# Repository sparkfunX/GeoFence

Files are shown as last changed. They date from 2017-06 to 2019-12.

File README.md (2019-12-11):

# GeoFence
A device to monitor when it is inside or outside various GPS waypoints.

# The GeoFence App is no longer supported
Unfortunately, Google has changed the way that they bill their Maps API and because we're no longer building the GeoFence hardware, 
we won't be updating the software. If you're looking for a way to create and enforce your own geofences, we encourage you to check out the [uBlox](https://learn.sparkfun.com/tutorials/getting-started-with-u-center-for-u-blox) products we now carry. If you still have a GeoFence board that you'd like to continue using, you have two options:

1. You can aqcuire your own [Google Maps API Key](https://developers.google.com/maps/documentation/javascript/get-api-key), 
replace our key string in the app source code (index.html line 77), and recompile the app in [electronjs](https://electronjs.org/).

2. You can construct your own configuration string using lat-long data from the source of your choosing and send it to the board using 
a serial terminal. Configuration strings are constructed as follows:

## Complete Configuration String

| Header | Zone 1 | Zone 2 | Zone 3 | Zone 4 | Footer | Chksum | Terminator |
| --- | --- | --- | --- | --- | --- | --- | --- |
| "$\n"  | | | | |  "^\n" | | "$" |

## Zone Configuration

### Null Zone
The device expects to see configurations for each zone, even if the zone is "unprogrammed". Unprogrammed zones are marked with the "X" flag.

| Header |
| ------ |
|  "X\n" |

### Rectangular Zone
Rectangular Boundaries are defined by their NorthEast and SouthWest corners. The Latitude and Longitude of each corner is fixed to 
6 digits of precision after the decimal. Rectangular Zones are marked with the "R" Flag.

| Header | NorthEast Lat | NorthEast Long | SouthWest Lat | SouthWest Long | 
| --- | --- | --- | --- | --- |
|  "R\n" | "xx.xxxxxx\n" |  "-x.xxxxxx\n" | "xxx.xxxxxx\n"| "xx.xxxxxx\n"  |

### Circular Zone
Circular Boundaries are defined by their center coordinate and their radius in meters, rounded to the nearest meter. 
Circular Zones are marked with the "C" flag.

| Header | Center Lat | Center Long | Radius Meters | 
| --- | --- | --- | --- |
|  "C\n" |"x.xxxxxx\n"|"-x.xxxxxx\n"| "xxx\n" |

### Checksum
Strings are transmitted with a checksum for integrity. The checksum is the sum of all character values in the string up to 
the checksum, modulo 256. It is calculated in the App thusly: 

```
  for(var i = 0; i < data.length; i++){
	 chksum = chksum + data.charCodeAt(i); 
  }
  
  chksum = chksum%256;
  ```
  
  The checksum value is written to a single byte and followed by a Line Feed ("\n")
  
### Serial Settings
The configuration string may be sent at any time at 9600 baud. The board will return with "$" if the configuration was succesful, if
the string did not pass checksum, it will return "!"

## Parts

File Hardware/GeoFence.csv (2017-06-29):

Id | Designator | Package | Quantity | Designation | Supplier and ref
1 | R12,R13 | R_0603 | 2 | 4.7k
2 | R4 | R_0603 | 1 | 1k
3 | FRAME1 | CREATIVE_COMMONS | 1 | FRAME-LETTER
4 | C7 | C_0603 | 1 | 2.2uF
5 | C8,C12,C14,C6 | C_0603 | 4 | 1.0uF
6 | C9,C10,C11,C13,C4 | C_0603 | 5 | 0.1uF
7 | J6 | 2X4 | 1 | CONN_04X2
8 | Q1 | RESONATOR-SMD-3.2X1.3 | 1 | 8/16/20MHz
9 | R9,R6,R7,R16 | R_0603 | 4 | 10k
10 | R10,R14,R8,R11 | R_0603 | 4 | 330
11 | R15,R2,R3 | R_0603 | 3 | 470
12 | U2 | SOT353 | 1 | 74LVC1G08SE
13 | U3 | SO16 | 1 | CH340G
14 | U5 | TQFP32-08 | 1 | ATMEGA328
15 | Y1 | CRYSTAL-SMD-3.2X2.5MM | 1 | 12MHz
16 | J4,J5 | 1X04 | 2 | CONN_04
17 | B1 | SparkX-6.8MM_COIN_CELL | 1 | COIN CELL
18 | C1,C2 | C_0603 | 2 | 10pF
19 | C3 | C_0603 | 1 | 10nF
20 | D1,D9 | LED_0603 | 2 | BLUE
21 | D2 | SparkFun-DiscreteSemi-SOD-323 | 1 | 0.5A/40V/420mV
22 | D5,D6,D7,D8 | LED_0603 | 4 | Green
23 | FB1 | L_0603 | 1 | 600Ohm/100MHz
24 | J1 | SparkX-U.FL | 1 | U.FL
25 | J2 | USB-B-MICRO-SMD | 1 | microB
26 | J3 | 2X3 | 1 | AVR_SPI_PROG_3X2PTH
27 | JP2,JP6 | FIDUCIAL-MICRO | 2 | FIDUCIALUFIDUCIAL
28 | JP5 | SMT-JUMPER_2_NC_TRACE_NO-SILK | 1 | ~
29 | L1 | L_0603 | 1 | 33nH/~5%/500mA
30 | R1,R19,R20 | R_0603 | 3 | 1K
31 | S1 | TACTILE_SWITCH_SMD_5.2MM | 1 | Reset
32 | U$1 | SparkX-SPARKX-LARGE | 1 | SPARKX-LOGO5
33 | U1 | SparkX-TITAN_X1_GPS | 1 | TITAN X1 GPS
34 | C15,C5 | C_0603 | 2 | 4.7uF
35 | D10 | SparkFun-DiscreteSemi-SOD-323 | 1 | BAT20J
36 | JP8 | JST-2-PTH | 1 | LiPo
37 | Q2 | SparkFun-DiscreteSemi-SOT23-3 | 1 | 2.5A/30V
38 | R17 | R_0603 | 1 | 2.0k
39 | U6 | SOT23-5 | 1 | MCP73831
40 | U4 | SOT23-5 | 1 | AP2112K-3.3V
41 | D3,D11 | LED_0603 | 2 | Yellow
42 | D4 | LED_0603 | 1 | GREEN
43 | D12 | LED_0603 | 1 | RED

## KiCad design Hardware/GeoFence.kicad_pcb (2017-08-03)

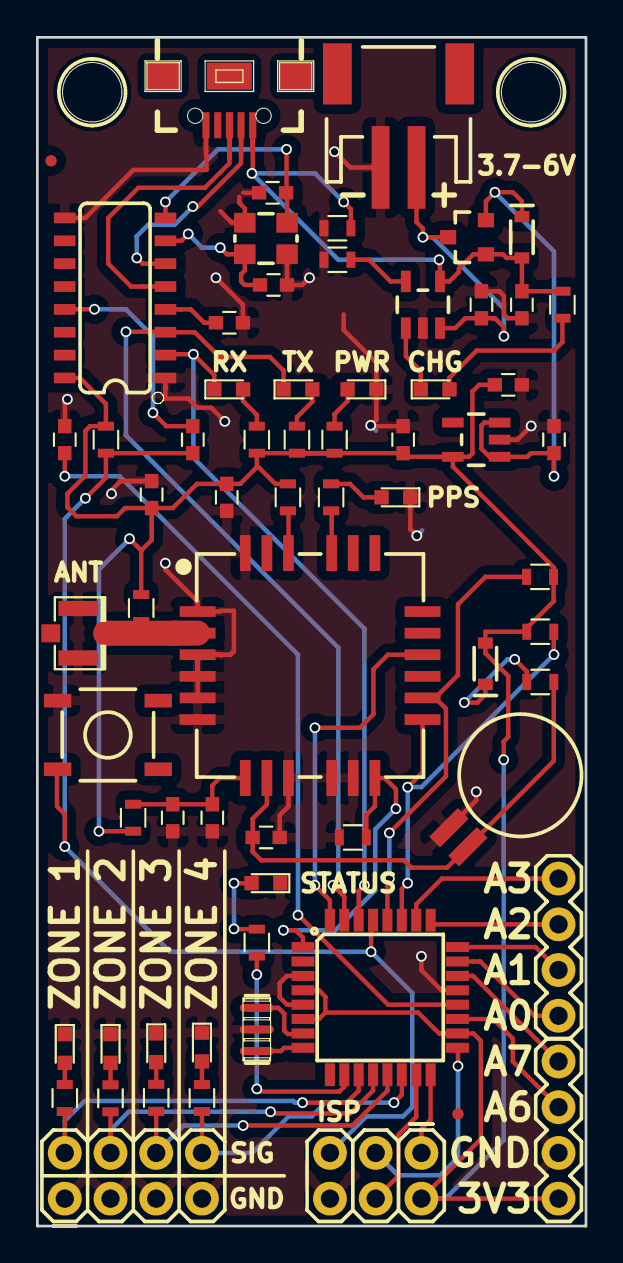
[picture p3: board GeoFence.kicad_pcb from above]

Board: 2 copper layers, 30.5 x 66.0 mm, 68 parts (0 on the bottom side), 53 nets.

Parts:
B1: COIN CELL; SparkX-6.8MM_COIN_CELL
C1, C2: 10pF; C_0603
C3: 10nF; C_0603
C4, C9, C10, C11, C13: 0.1uF; C_0603
C5, C15: 4.7uF; C_0603
C6, C8, C12, C14: 1.0uF; C_0603
C7: 2.2uF; C_0603
D1, D5, D6, D7, D8, D9: Blue; LED_0603
D2: 0.5A/40V/420mV; SparkFun-DiscreteSemi-SOD-323
D3, D11: Yellow; LED_0603
D4: GREEN; LED_0603
D10: BAT20J; SparkFun-DiscreteSemi-SOD-323
D12: Red; LED_0603
FB1: 600Ohm/100MHz; L_0603
H1, H2: STAND-OFF
J1: U.FL; SparkX-U.FL
J2: microB; USB-B-MICRO-SMD
J3: AVR_SPI_PROG_3X2PTH; 2X3
J4, J5: CONN_04; 1X04
J6: CONN_04X2; 2X4
JP2, JP6: FIDUCIALUFIDUCIAL; FIDUCIAL-MICRO
JP8: LiPo; JST-2-SMD
L1: 33nH/~5%/500mA; L_0603
Q1: 8/16/20MHz; RESONATOR-SMD-3.2X1.3
Q2: 2.5A/30V; SparkFun-DiscreteSemi-SOT23-3
R1, R4, R17, R18: 1k; R_0603
R2, R3, R8, R10, R11, R14, R15: 470; R_0603
R5, R6, R7, R9: 10k; R_0603
R12, R13: 4.7k; R_0603
R16: 2.0k; R_0603
S1: Reset; TACTILE_SWITCH_SMD_5.2MM
U1: TITAN X1 GPS; SparkX-TITAN_X1_GPS
U3: CH340G; SO16
U4: AP2112K-3.3V; SOT23-5
U5: ATMEGA328; TQFP32-08
U6: MCP73831; SOT23-5
Y1: 12MHz; CRYSTAL-SMD-3.2X2.5MM

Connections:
+3V3: C4.1, C7.1, C11.1, C12.1, D2.A, FB1.1, J3.2, J4.1, L1.2, R1.1, R2.2, R6.1, R9.2, R12.2, R13.2, R18.1, U3.16, U4.5, U5.4, U5.6, U5.18
+5V: C15.1, D10.A, J2.VBUS, Q2.1, R5.1, R17.1, U6.4
/A0: J5.1, U5.23
/A1: J5.2, U5.24
/A2: J5.3, U5.25
/A3: J5.4, U5.26
/A6: J4.3, U5.19
/A7: J4.4, U5.22
/ATRESET: C9.1, J3.5, R6.2, S1.3, U5.29
/BACKUP: B1.+, C8.1, R4.2, U1.8
/D7: J6.2, R8.1, U5.11
/D8: J6.4, R10.1, U5.12
/D9: J6.6, R11.1, U5.13
/D10: J6.8, R14.1, U5.14
/DTR: C9.2, U3.13
/INT: U1.16, U5.32
/MISO: J3.1, U5.16
/MOSI: J3.4, U5.15
/PPS: R3.2, U1.21
/RXI: D4.1, U3.2, U5.30
/SCK: J3.3, U5.17
/SCL: R12.1, U1.14, U5.28
/SDA: R13.1, U1.13, U5.27
/STATUS: R15.2, U5.10
/TXO: D3.1, U3.3, U5.31
/WAKE: R7.1, U1.12, U5.1
/~RESET: R9.1, U1.22
GND: B1.-, C1.2, C2.2, C3.2, C4.2, C5.2, C6.2, C7.2, C8.2, C10.2, C11.2, C12.2, C13.2, C14.2, C15.2, D1.1, D5.1, D6.1, D7.1, D8.1, D9.1, D12.1, J1.1, J1.2, J2.GND, J3.6, J4.2, J6.1, J6.3, J6.5, J6.7, JP8.1, Q1.2, R5.2, R7.2, R16.2, S1.1, U1.1, U1.3, U1.4, U1.5, U1.6, U1.9, U1.10, U1.11, U1.24, U3.1, U3.9, U4.2, U5.3, U5.5, U5.21, U6.2, Y1.2, Y1.4
unnamed: C1.1, U3.7, Y1.3
unnamed: C2.1, U3.8, Y1.1
unnamed: C3.1, U3.4
unnamed: C6.1, D10.C, Q2.2, U4.1, U4.3
unnamed: C10.1, U5.20
unnamed: C13.1, C14.1, FB1.2, U1.7
unnamed: D1.2, R3.1
unnamed: D2.C, R4.1
unnamed: D3.2, R1.2
unnamed: D4.2, R2.1
unnamed: D5.2, R8.2
unnamed: D6.2, R10.2
unnamed: D7.2, R11.2
unnamed: D8.2, R14.2
unnamed: D9.2, R15.1
unnamed: D11.1, U6.1
unnamed: D11.2, R17.2
unnamed: D12.2, R18.2
unnamed: J1.FEED, L1.1, U1.2
unnamed: J2.D+, U3.5
unnamed: J2.D-, U3.6
unnamed: Q1.1, U5.7
unnamed: Q1.3, U5.8
unnamed: R16.1, U6.5
V_BATT: C5.1, JP8.2, Q2.3, U6.3

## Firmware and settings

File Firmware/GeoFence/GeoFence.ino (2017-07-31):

/*
  GeoFence Board Firmware
  By: Nick Poole
  SparkFun Electronics
  Date: July 10th, 2017
  License: This code is public domain but you buy me a beer if you use this and we meet someday (Beerware license).

  GeoFence has an ATmega running at 8MHz/3.3V. Select 'Pro Mini @ 3.3V/8MHz' from Boards menu to program
  the device.
*/

#include <SparkFun_I2C_GPS_Arduino_Library.h> //Use Library Manager or download here: https://github.com/sparkfun/SparkFun_I2C_GPS_Arduino_Library
I2CGPS myI2CGPS; //Hook object to the library

#include <TinyGPS++.h> //From: https://github.com/mikalhart/TinyGPSPlus
TinyGPSPlus gps; //Declare gps object

#include <EEPROM.h>

//zoneX[] contains the 4 GPS coordinates for each rectangular zone, or 2 coordinates
//and radius for a circular zone.
double zone1[5];
double zone2[5];
double zone3[5];
double zone4[5];
char zoneType[4];

//Zone information
//zoneX[0] = North East Lat corner of the rectangle
//1 = NE Long
//2 = SW Lat
//3 = SW Long
//or
//zoneX[2] = Center Lat of the circle
//3 = Center Long of the circle
//4 = Radius of circle

byte STAT_LED = 6; //Blue status LED next to ATmega
byte zoneIOPin[] = {7, 8, 9, 10}; //Four zone LEDs
byte STAT_SYSTEM = A0; //Goes high when system has a valid lock and Zone pins are valid.

boolean ZONES_EMPTY = 1; //Used for system status LED to alert user to "No Zones Programmed" state

#define MODE_WAITING_FOR_LOCK 0
#define MODE_GPS_LOCKED 1

byte systemMode; //Keeps track of what mode we are in so as to control the status LED

void setup()
{
  //Setup I/O
  pinMode(STAT_LED, OUTPUT);
  digitalWrite(STAT_LED, HIGH); //Indicate we are waiting for GPS data
  pinMode(STAT_SYSTEM, OUTPUT);
  digitalWrite(STAT_SYSTEM, LOW); //Indicate zone pins are not yet valid

  //Configure Zone LEDs
  for (byte z = 0; z < 4; z++)
  {
    pinMode(zoneIOPin[z], OUTPUT);
    digitalWrite(zoneIOPin[z], LOW);
  }

  //ATmega is running at 8MHz(3.3V). Serial above 57600bps is not good.
  Serial.begin(9600);

  //Load zone data from EEPROM
  loadZoneData();

  //Print the zoneType for each zone for troubleshooting
  for(int i=0; i<4; i++){
  Serial.print("Zone ");
  Serial.print(i+1);
  Serial.print(" Type: ");
  Serial.println(zoneType[i]);
  }

  //Check if there are no zones programmed and alert the user
  for(int i=0; i<4; i++){
    if(zoneType[i]!='X'){ZONES_EMPTY=0;}
  }
  if(ZONES_EMPTY){Serial.println("There are no zones programmed! No tests will be performed!");}

    //Start GPS Module comms
  if (myI2CGPS.begin() == false)
  {
    //GPS communication failure
    Serial.println("GPS module failed to respond. Please contact support.");

    //Blink STAT_LED and Zone LEDs to indicate fault
    while (1) //Freeze!
    {
      digitalWrite(zoneIOPin[0], HIGH);
      digitalWrite(zoneIOPin[1], LOW);
      digitalWrite(zoneIOPin[2], HIGH);
      digitalWrite(zoneIOPin[3], LOW);
      digitalWrite(STAT_LED, HIGH);
      delay(1000);
      digitalWrite(zoneIOPin[0], LOW);
      digitalWrite(zoneIOPin[1], HIGH);
      digitalWrite(zoneIOPin[2], LOW);
      digitalWrite(zoneIOPin[3], HIGH);
      digitalWrite(STAT_LED, LOW);
      delay(1000);
    }
  }

  systemMode = MODE_WAITING_FOR_LOCK;

  //Twiddle the zone LEDs to indicate we are ready to go
  for (byte x = 0 ; x < 4 ; x++)
    digitalWrite(zoneIOPin[x], HIGH);
  delay(500);
  for (byte x = 0 ; x < 4 ; x++)
    digitalWrite(zoneIOPin[x], LOW);

  Serial.println("GeoFence v1.0 Online");
}

void loop()
{
  // Do GeoFence Things
  while (myI2CGPS.available()) //available() returns the number of new bytes available from the GPS module
  {
    gps.encode(myI2CGPS.read()); //Feed the GPS parser
  }

  if (gps.time.isUpdated() && gps.location.isValid()) //Check to see if new GPS info is available
  {
    Serial.println("Valid Data -> Updating");
    updateGeofence();
  }

  //Once we have lock, go to new STAT_LED LED mode
  if (gps.location.isValid())
  {
    systemMode = MODE_GPS_LOCKED;
    digitalWrite(STAT_SYSTEM, HIGH); //Indicate that zone pins are valid
  }
  else
  {
    systemMode = MODE_WAITING_FOR_LOCK;
    digitalWrite(STAT_SYSTEM, LOW); //Indicate that zone pins are not currently valid
  }

  // Check for a new config
  if (Serial.available()) {
    while (Serial.read() != '$') {};
    String configString = Serial.readStringUntil('$');

    if (parseNewZoneData(configString) == true)
    {
      //Twiddle the zone LEDs to indicate we have successfully received the new zone data
      for (byte j = 0 ; j < 3 ; j++)
      {
        for (byte x = 0 ; x < 4 ; x++)
        {
          digitalWrite(zoneIOPin[x], HIGH);
          delay(100);
          digitalWrite(zoneIOPin[x], LOW);
        }
      }
    }
  }

  //Control the status LED
  if (systemMode == MODE_WAITING_FOR_LOCK)
  {
    if ((millis() / 1000) % 2 == 0) //Blink LED every other second
      digitalWrite(STAT_LED, HIGH);
    else
      digitalWrite(STAT_LED, LOW);
  }
  else if (systemMode == MODE_GPS_LOCKED)
  {
    digitalWrite(STAT_LED, HIGH);
  };
  //This setting overrides the others
  if (ZONES_EMPTY)
  {
    digitalWrite(STAT_LED, LOW);
  } //End STAT_LED control

}

//Reads configuration data over serial port
//Records checksum valid data to EEPROM
//Returns true if four zones successfully received
boolean parseNewZoneData(String configString)
{
  //Clear current EEPROM settings
  zeroEEPROM();

  // Receive and Verify a configuration
  String linebuffer;
  int addr = 0;
  int strIndex = 0;
  int inByte = 0;
  boolean checksumPass = 0;
  int attempts = 0;

  while (!checksumPass && attempts < 5) {

    attempts++;

    digitalWrite(STAT_LED, LOW);

    strIndex++;

    //Serial.println("parsing...");

    for (int zone = 0; zone < 4; zone++) {
      inByte = configString.charAt(strIndex); // Should contain Zone 1 Type (R/C/X)
      strIndex++; strIndex++;

      switch (inByte) {

        case 'R': //Zone is rectangular

          addr = 0 + (zone * 20);
          linebuffer.remove(0);
          while (configString.charAt(strIndex) != 10) {
            linebuffer += configString.charAt(strIndex);
            strIndex++;
          }
          strIndex++;
          str_to_double_to_EEPROM(linebuffer, addr);

          addr = 4 + (zone * 20);
          linebuffer.remove(0);
          while (configString.charAt(strIndex) != 10) {
            linebuffer += configString.charAt(strIndex);
            strIndex++;
          }
          strIndex++;
          str_to_double_to_EEPROM(linebuffer, addr);

          addr = 8 + (zone * 20);
          linebuffer.remove(0);
          while (configString.charAt(strIndex) != 10) {
            linebuffer += configString.charAt(strIndex);
            strIndex++;
          }
          strIndex++;
          str_to_double_to_EEPROM(linebuffer, addr);

          addr = 12 + (zone * 20);
          linebuffer.remove(0);
          while (configString.charAt(strIndex) != 10) {
            linebuffer += configString.charAt(strIndex);
            strIndex++;
          }
          strIndex++;
          str_to_double_to_EEPROM(linebuffer, addr);

          //Zero the circle-only bytes
          addr = 16 + (zone * 20);
          EEPROM.put(addr, long(0L));          

          break;

        case 'C': //Zone is circular

          //Zero the rectangle-only bytes
          addr = 0 + (zone * 20); 
          EEPROM.put(addr, long(0L));
          addr = 4 + (zone * 20);
          EEPROM.put(addr, long(0L));        

          addr = 8 + (zone * 20);
          linebuffer.remove(0);
          while (configString.charAt(strIndex) != 10) {
            linebuffer += configString.charAt(strIndex);
            strIndex++;
          }
          strIndex++;
          str_to_double_to_EEPROM(linebuffer, addr);

          addr = 12 + (zone * 20);
          linebuffer.remove(0);
          while (configString.charAt(strIndex) != 10) {
            linebuffer += configString.charAt(strIndex);
            strIndex++;
          }
          strIndex++;
          str_to_double_to_EEPROM(linebuffer, addr);

          addr = 16 + (zone * 20);
          linebuffer.remove(0);
          while (configString.charAt(strIndex) != 10) {
            linebuffer += configString.charAt(strIndex);
            strIndex++;
          }
          strIndex++;
          str_to_double_to_EEPROM(linebuffer, addr);

          break;

        case 'X': //Zone is undefined, fill with zeroes
          addr = 0 + (zone * 20);
          EEPROM.put(addr, long(0L));
          addr = 4 + (zone * 20);
          EEPROM.put(addr, long(0L));
          addr = 8 + (zone * 20);
          EEPROM.put(addr, long(0L));
          addr = 12 + (zone * 20);
          EEPROM.put(addr, long(0L));
          addr = 16 + (zone * 20);
          EEPROM.put(addr, long(0L));
          break;

      }
    }

    //Serial.println("parsed");

    strIndex = strIndex + 2;
    linebuffer.remove(0);
    while (configString.charAt(strIndex) != 10) {
      linebuffer += configString.charAt(strIndex);
      strIndex++;
    }

    //Serial.print("checksum received: ");
    //Serial.println(linebuffer.toInt());

    int calcSum = 0;

    //Serial.println("ready to calculate sum");

    for (int r = 0; configString.charAt(r) != '^'; r++) {
      calcSum = calcSum + configString.charAt(r);
    }

    calcSum = calcSum + 140;
    calcSum = calcSum % 256;

    //Serial.print("checksum calculated: ");
    //Serial.println(calcSum);

    if (linebuffer.toInt() == calcSum)
    {
      for (byte x = 0 ; x < 5 ; x++)
      {
        digitalWrite(STAT_LED, HIGH);
        delay(200);
        digitalWrite(STAT_LED, LOW);
        delay(200);
      }

      Serial.print("$\n"); //Checksum passed
      return (true); //We're done!
    } else {
      Serial.print("!\n"); //Checksum failed
      linebuffer.remove(0);
      addr = 0;
      strIndex = 0;
      inByte = 0;
      delay(500);
    }
  }

  return (false); //Checksum failed and we exhausted attempts
}

//Load the zone information and type of zone (rectangle, circle, other) from NVM
void loadZoneData() {
  //Get zones
  for (int i = 0; i < 5; i++) {
    EEPROM.get(i * 4, zone1[i]);
  }
  for (int i = 0; i < 5; i++) {
    EEPROM.get(20 + (i * 4), zone2[i]);
  }
  for (int i = 0; i < 5; i++) {
    EEPROM.get(40 + (i * 4), zone3[i]);
  }
  for (int i = 0; i < 5; i++) {
    EEPROM.get(60 + (i * 4), zone4[i]);
  }

  //Error check zone data
  //If unit does not have any location data (first time power on)
  //then zero out the EEPROM
  if (isnan(zone1[0])) zeroEEPROM();
  if (zone1[0] > 360.0 || zone1[0] < -360.0) zeroEEPROM();

  //Set zone types based on zoneX data
  //00 = No coordinates
  //01 = Circle
  //1x = Rectangle
  //255/255 = EEPROM initial state/not set
  if (zone1[0] == 0 && zone1[2] == 0) {
    zoneType[0] = 'X'; //Not yet filled with coordinates
  }
  else if (zone1[0] == 0 && zone1[2] != 0) {
    zoneType[0] = 'C'; //Circle
  }
  else if (zone1[0] != 0) {
    zoneType[0] = 'R'; //Rectangle
  }

  if (zone2[0] == 0 && zone2[2] == 0) {
    zoneType[1] = 'X';
  }
  if (zone2[0] == 0 && zone2[2] != 0) {
    zoneType[1] = 'C';
  }
  if (zone2[0] != 0) {
    zoneType[1] = 'R';
  }

  if (zone3[0] == 0 && zone3[2] == 0) {
    zoneType[2] = 'X';
  }
  if (zone3[0] == 0 && zone3[2] != 0) {
    zoneType[2] = 'C';
  }
  if (zone3[0] != 0) {
    zoneType[2] = 'R';
  }

  if (zone4[0] == 0 && zone4[2] == 0) {
    zoneType[3] = 'X';
  }
  if (zone4[0] == 0 && zone4[2] != 0) {
    zoneType[3] = 'C';
  }
  if (zone4[0] != 0) {
    zoneType[3] = 'R';
  }
}

void str_to_double_to_EEPROM(String str, int addr) {
  double bytes = str.toDouble();
  EEPROM.put(addr, bytes);
}

void updateGeofence() {

  for (int zone = 0; zone < 4; zone++) {

    switch (zoneType[zone]) {

      case 'R':
        Serial.print("Checking Rectangular Zone ");
        Serial.println(zone+1);//Zones are only zero-indexed in firmware
        digitalWrite(zoneIOPin[zone], checkRectangle(zone));
        break;

      case 'C':
        Serial.print("Checking Circular Zone ");
        Serial.println(zone+1);//Zones are only zero-indexed in firmware
        digitalWrite(zoneIOPin[zone], checkCircle(zone));
        break;

    }
  }
}

//Check to see if our current location is inside a given zone number
//Returns true if we are inside the zone
boolean checkRectangle(int zone) {

  double swLat, swLng, neLat, neLng;

  switch (zone) {

    case 0:
      neLat = zone1[0];
      neLng = zone1[1];
      swLat = zone1[2];
      swLng = zone1[3];
      break;

    case 1:
      neLat = zone2[0];
      neLng = zone2[1];
      swLat = zone2[2];
      swLng = zone2[3];
      break;

    case 2:
      neLat = zone3[0];
      neLng = zone3[1];
      swLat = zone3[2];
      swLng = zone3[3];
      break;

    case 3:
      neLat = zone4[0];
      neLng = zone4[1];
      swLat = zone4[2];
      swLng = zone4[3];
      break;
  }

  if (neLng < swLng) { //If this is true, we're stradling the 180th. This is bad for the maths.

    //We must slice the box into two boxes with the max of one being 180 and the min of the other being -180

    boolean zoneSubA = (min(neLng, swLng) > gps.location.lng() && gps.location.lng() > -180 && min(neLat, swLat) < gps.location.lat() && gps.location.lat() < max(neLat, swLat));
    boolean zoneSubB = (max(neLng, swLng) < gps.location.lng() && gps.location.lng() < 180 && min(neLat, swLat) < gps.location.lat() && gps.location.lat() < max(neLat, swLat));

    //If the current location falls into either of these halves, we're in the zone

    if (zoneSubA || zoneSubB) {
      return(true);
    } else {
      return(false); //If not, return 0
    }

  } else { //In a more reasonable locale

    //Nothing too fancy here, if our point is between the top and bottom of the rectangle AND between the sides... we're in!

    Serial.println("Performing Box Test");

    Serial.print("Min(x1,x2): ");
    Serial.println(min(neLat, swLat), 6);
    Serial.print("Lat: ");
    Serial.println(gps.location.lat(), 6);
    Serial.print("Max(x1,x2): ");
    Serial.println(max(neLat, swLat), 6);
    Serial.print("Min(y1,y2): ");
    Serial.println(min(neLng, swLng), 6);
    Serial.print("Lng: ");
    Serial.println(gps.location.lng(), 6);
    Serial.print("Max(y1,y2): ");
    Serial.println(max(neLng, swLng), 6);

    if (min(neLat, swLat) < gps.location.lat() && gps.location.lat() < max(neLat, swLat) && min(neLng, swLng) < gps.location.lng() && gps.location.lng() < max(neLng, swLng)) {
      Serial.println("Box Test Passed");
      return(true);
    } else {
      Serial.println("Box Text Failed");
      return(false); //If not, return 0
    }
  }
}

boolean checkCircle(int zone) {

  double centerLat, centerLng, zoneRadius;

  switch (zone) {

    case 0:
      centerLat = zone1[2];
      centerLng = zone1[3];
      zoneRadius = zone1[4];
      break;

    case 1:
      centerLat = zone2[2];
      centerLng = zone2[3];
      zoneRadius = zone2[4];
      break;

    case 2:
      centerLat = zone3[2];
      centerLng = zone3[3];
      zoneRadius = zone3[4];
      break;

    case 3:
      centerLat = zone4[2];
      centerLng = zone4[3];
      zoneRadius = zone4[4];
      break;
  }

  double distanceToCenter =
    TinyGPSPlus::distanceBetween(
      gps.location.lat(),
      gps.location.lng(),
      centerLat,
      centerLng);

  Serial.println("Performing Circle Test");
  Serial.print("Distance To: ");
  Serial.println(distanceToCenter);
  Serial.print("Radius: ");
  Serial.println(zoneRadius);

  if (distanceToCenter < zoneRadius) {
    Serial.println("Circle Test Passed");
    return 1;
  } else {
    Serial.println("Circle Test Failed");
    return 0;
  }
}

//This is called when a new board is freshly programmed
//We need to zero out the various EEPROM spots from their default 255
//Reading a double from 0xFFFFFFFF in EEPROM = not a number (nan)
void zeroEEPROM(void)
{
  Serial.println("Setting EEPROM to zero");

  //Zero out the 4 bytes for each of the 5 zones
  for (byte i = 0 ; i < 5 * 4 ; i++)
  {
    EEPROM.write(i, 0);
  }
}

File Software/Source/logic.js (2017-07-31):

var activeLoc = 0;
var boundaryOne = 0;
var boundaryTwo = 0;
var boundaryThree = 0;
var boundaryFour = 0;
var boundaryIsCirc = [0, 1, 1, 1, 1];
var map = 0;
var SerialPort = require('serialport');
var port;
var data;

function initMap() {

  map = new google.maps.Map(document.getElementById('map'), {
    zoom: 12,
    center: {
      lat: 40.014986,
      lng: -105.270546
    }
  });

  map.addListener('click', function(e) {
    placeMarkerAndPanTo(e.latLng, map);
  });

  var geocoder = new google.maps.Geocoder();

  document.getElementById('submit').addEventListener('click', function() {
    geocodeAddress(geocoder, map);
  });

}

function serialSwitch() {
	
	port = new SerialPort(document.getElementById("serialPortNum").value, {
		parser: SerialPort.parsers.readline('\n'),
		baudRate: 9600
		});
	
	port.on('data', function(x){
		switch(x){
			
			case '!':
				port.write(data);
				statusBar("failed checksum... trying again...");
				break;
				
			case '$':
				statusBar("configuration successfully written to board!");
				break;
			
			default:
			
				break;
			
		}
	});
		
	statusBar("opened serial port on " + document.getElementById("serialPortNum").value + "...");
	// Device will reset on serial connection. Keep user from trying to upload config too soon.
	document.getElementById("logData").disabled = true;
	setTimeout(function(){document.getElementById("logData").disabled = false;}, 3000);
}

function serialClose() {
	
	port.close();
	statusBar("active serial port closed");
	
}

function findDevices() {
	
	statusBar("searching for devices...");
	
	document.getElementById("serialPortNum").innerHTML = '';
	SerialPort.list(function (err, ports) {
		ports.forEach(function(port) {
			var portEntry = document.createElement('option');
			portEntry.value = port.comName;
			portEntry.innerHTML = port.comName;
			document.getElementById("serialPortNum").appendChild(portEntry);
			console.log(port.comName);
  });
});	

	setTimeout(function() {
		statusBar("found " + document.getElementById("serialPortNum").childNodes.length + " serial devices...");
	}, 1000);
}

function placeMarkerAndPanTo(latLng, map) {

  var bounds = {
    north: latLng.lat() + .0008,
    south: latLng.lat() - .0008,
    east: latLng.lng() + .0008,
    west: latLng.lng() - .0008
  };

  switch (activeLoc) {

    case 0:
      break;

    case 1:

      if (boundaryOne != 0) {

        if (boundaryIsCirc[1] == 0) {
          boundaryOne.setBounds(bounds);
          boundaryOne.setMap(map);
        } else {
          boundaryOne.setCenter(latLng);
          boundaryOne.setMap(map);
        }

      } else {

        if (boundaryIsCirc[1] == 0) {
          boundaryOne = new google.maps.Rectangle({
            bounds: bounds,
            editable: true,
            fillColor: '#FF0000',
          });
          boundaryOne.addListener('bounds_changed', function() {
            updateCoords('R', 1);
          });
        } else {
          boundaryOne = new google.maps.Circle({
            fillColor: '#FF0000',
            map: map,
            center: latLng,
            editable: true,
            radius: 100
          });
          boundaryOne.addListener('center_changed', function() {
            updateCoords('C', 1);
          });
          boundaryOne.addListener('radius_changed', function() {
            updateCoords('C', 1);
          });
        }
        boundaryOne.setMap(map);
      }
      break;

    case 2:

      if (boundaryTwo != 0) {

        if (boundaryIsCirc[2] == 0) {
          boundaryTwo.setBounds(bounds);
          boundaryTwo.setMap(map);
        } else {
          boundaryTwo.setCenter(latLng);
          boundaryTwo.setMap(map);
        }

      } else {

        if (boundaryIsCirc[2] == 0) {
          boundaryTwo = new google.maps.Rectangle({
            bounds: bounds,
            editable: true,
            fillColor: '#00FF00',
          });
          boundaryTwo.addListener('bounds_changed', function() {
            updateCoords('R', 2);
          });
        } else {
          boundaryTwo = new google.maps.Circle({
            fillColor: '#00FF00',
            map: map,
            center: latLng,
            editable: true,
            radius: 100
          });
          boundaryTwo.addListener('center_changed', function() {
            updateCoords('C', 2);
          });
          boundaryTwo.addListener('radius_changed', function() {
            updateCoords('C', 2);
          });
        }
        boundaryTwo.setMap(map);
      }
      break;

    case 3:

      if (boundaryThree != 0) {

        if (boundaryIsCirc[3] == 0) {
          boundaryThree.setBounds(bounds);
          boundaryThree.setMap(map);
        } else {
          boundaryThree.setCenter(latLng);
          boundaryThree.setMap(map);
        }

      } else {

        if (boundaryIsCirc[3] == 0) {
          boundaryThree = new google.maps.Rectangle({
            bounds: bounds,
            editable: true,
            fillColor: '#FFFF00',
          });
          boundaryThree.addListener('bounds_changed', function() {
            updateCoords('R', 3);
          });
        } else {
          boundaryThree = new google.maps.Circle({
            fillColor: '#FFFF00',
            map: map,
            center: latLng,
            editable: true,
            radius: 100
          });
          boundaryThree.addListener('center_changed', function() {
            updateCoords('C', 3);
          });
          boundaryThree.addListener('radius_changed', function() {
            updateCoords('C', 3);
          });
        }
        boundaryThree.setMap(map);
      }
      break;

    case 4:

      if (boundaryFour != 0) {

        if (boundaryIsCirc[4] == 0) {
          boundaryFour.setBounds(bounds);
          boundaryFour.setMap(map);
        } else {
          boundaryFour.setCenter(latLng);
          boundaryFour.setMap(map);
        }

      } else {

        if (boundaryIsCirc[4] == 0) {
          boundaryFour = new google.maps.Rectangle({
            bounds: bounds,
            editable: true,
            fillColor: '#0000FF',
          });
          boundaryFour.addListener('bounds_changed', function() {
            updateCoords('R', 4);
          });
        } else {
          boundaryFour = new google.maps.Circle({
            fillColor: '#0000FF',
            map: map,
            center: latLng,
            editable: true,
            radius: 100
          })
          boundaryFour.addListener('center_changed', function() {
            updateCoords('C', 4);
          });
          boundaryFour.addListener('radius_changed', function() {
            updateCoords('C', 4);
          });
        }
        boundaryFour.setMap(map);
      }
      break;

  }

  map.panTo(latLng);
}
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

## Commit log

2017-06-23 Finished Schematic
    Got the rest of the EAGLE to KiCad conversions done and got everything
    airwired properly (Hell is a real place called "CvPcb"). Beginnings of a
    layout are happening now.
    [GeoFence.sch]
2017-06-26 Moved Reference labels to drwg layer
    The board layout is beginning to take form
    [GeoFence.kicad_pcb, GeoFence.sch]
2017-06-27 Routing
    Started Routing
    [GeoFence.kicad_pcb, GeoFence.sch]
2017-06-27 Ready for Review
    [GeoFence.kicad_pcb]
2017-06-29 Design Review Changes
    [GeoFence.csv, GeoFence.kicad_pcb, GeoFence.sch]
2017-06-29 Ready for Panelization
    [GeoFence.kicad_pcb]
2017-06-29 Ready for Panelization
    For real this time, though
    [GeoFence.kicad_pcb]
2017-07-05 Panel Update
    [GeoFence-panel-B.Mask.gbs, GeoFence-panel-B.SilkS.gbo, GeoFence-panel-Bottom.gbl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]
2017-07-13 Adding STAT LED indicator modes
2017-07-17 Adding nan catch, sets EEPROM to 0.0 at first power on.
2017-07-17 Adding system valid pin
    When we have a lock, push pin A0 to high. When not valid, A0 is low.
2017-07-17 Adding startup and download indication to zone LEDs
    Zone LEDs will blink cylon when power up or when new data is downloaded.
2017-07-31 Formware fix
    Properly zeroes unused EEPROM bytes and alerts user when no zones are
    programmed.
    [GeoFence.ino]
2017-07-31 Software Fixes
    Added a button to close the active serial port as well as a 3 second
    lockout on the config button after opening the port (to allow device
    time to reset)
    [logic.js]
2017-08-03 Removed headers from paste layer / New Gerbers
    [GeoFence-panel-B.Mask.gbs, GeoFence-panel-B.SilkS.gbo, GeoFence-panel-Bottom.gbl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]
